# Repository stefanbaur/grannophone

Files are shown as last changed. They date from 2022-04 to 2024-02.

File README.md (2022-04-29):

# Grannophone

This is the repository for Grannophone code snippets and hardware plans.

The main project website can be found at https://www.grannophone.de

Shield: [][cc-by-nc-sa]

This work is licensed under a
[Creative Commons Attribution-NonCommercial-ShareAlike 4.0 International License][cc-by-nc-sa].

[][cc-by-nc-sa]

[cc-by-nc-sa]: http://creativecommons.org/licenses/by-nc-sa/4.0/
[cc-by-nc-sa-image]: https://licensebuttons.net/l/by-nc-sa/4.0/88x31.png
[cc-by-nc-sa-shield]: https://img.shields.io/badge/License-CC%20BY--NC--SA%204.0-lightgrey.svg

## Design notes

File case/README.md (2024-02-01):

# Grannophone plywood case

This directory contains the plans for a plywood case.

Note that this is a work in progress. Most sheets should be usable already, but may lack information about where to drill holes when using a fretsaw/scrollsaw, and where to place screws.
The sheets *should* work with a lasercutter, too (if you use the SVG versions instead of the PDF ones) - feedback welcome!
Note that for lasercutting, you should use the individual SVG files and arrange them to match the size of the plywood sheets you have available. We tried auto-generating merged SVGs for the more common sizes, but the merge tool never really worked.

At present, the base model consists of the following sheets:

- scale check - print/lasercut this first, to check that your printer is printing/your lasercutter ist cutting everything to scale (for lasercutting: if you don't want to waste a sheet of plywood, check if your lasercutter's beam intensity can be set low enough to cut/engrave paper without setting it on fire)
	- sheet_0.pdf

- telephone hook for the Digitus USB telephone receiver/headset
	- sheet_1_digitus.pdf
	- sheet_2_digitus.pdf
	- sheet_3_digitus.pdf - this sheet is needed twice! As with sheets 5 and 6 from the siedle_noamp series, you can simply attach two sheets (good sides facing each other) with masking tape and cut two sheets at the same time.
        - sheet_3_digitus_gespiegelt.pdf - this is a mirrored and partially stripped version of sheet 3 for easier lasercutting.

- telephone hook for the OpisTech telephone receiver/handset (with t-coil hearing aid support)
	- sheet_1_opistech.pdf
	- sheet_2_opistech.pdf
	- sheet_3_opistech.pdf - this sheet is needed twice! As with sheets 5 and 6 from the siedle_noamp series, you can simply attach two sheets (good sides facing each other) with masking tape and cut two sheets at the same time.
        - sheet_3_opistech_gespiegelt.pdf - this is a mirrored and partially stripped version of sheet 3 for easier lasercutting.

- base plates to accommodate two Siedle speakers, connected directly to the SBC, no amplifier
	- sheet_4_siedle_noamp.pdf
	- sheet_5_siedle_noamp.pdf
	- sheet_6_siedle_noamp.pdf - place this sheet on top of sheet 5, firmly secure them by wrapping them with masking tape, and start drilling/sawing/filing - this will help reduce splintering, and the affected areas on sheet 5 will be cut out later on anyway.

- base plates to accommodate two Visaton K50 WP speakers, connected directly to the SBC (or via amplifier, if you find one that works with them)
	- sheet_4_visaton_waveshare.pdf
	- sheet_5_visaton.pdf - place this sheet on top of sheet 4, it is exactly the same, except for missing the cutout for the audio plug that's on sheet_4_visaton.pdf (and you could actually cut that out of sheet_5_visaton.pdf as well, it wouldn't matter)
	- sheet_6_visaton_waveshare.pdf - place this sheet on top of sheets 4 and 5, firmly secure all of them by wrapping them with masking tape, and start drilling/sawing/filing - this will help reduce splintering, and the affected areas on sheets 4 and 5 will be cut out later on anyway.

- base plates to accommodate two VECO 40KS04PN-1 speakers, connected to a DAC/amplifier hat (e.g. HiFiBerry MiniAmp, or WaveShare WM8960) 
	- sheet_4_veco.pdf - place this sheet on top of sheet 5, as sheets 4 and 6 need the same octagonal cutouts (sheet 4 has some connections between them, though, so you will need to work on that separately)
	- sheet_5_veco.pdf - this sheet has rectangular cutouts and is thus the least critical of them all
	- sheet_6_veco.pdf - place this sheet on top of sheets 4 and 5, firmly secure all of them by wrapping them with masking tape, and start drilling/sawing/filing - this will help reduce splintering, and the affected areas on sheets 4 and 5 will be cut out later on anyway.

- base plates to accommodate two WaveShare WM8960 speakers, connected to the WaveShare amplifier hat
	- sheet_4_visaton_waveshare.pdf
	- sheet_5_waveshare.pdf - place this sheet on top of sheet 4, it is exactly the same, except for missing the cutout for the audio plug that's on sheet_4_visaton.pdf (and you could actually cut that out of sheet_5_visaton.pdf as well, it wouldn't matter)
	- sheet_6_visaton_waveshare.pdf - place this sheet on top of sheets 4 and 5, firmly secure all of them by wrapping them with masking tape, and start drilling/sawing/filing - this will help reduce splintering, and the affected areas on sheets 4 and 5 will be cut out later on anyway.

- currently generic parts
	- sheet_7.pdf
	- sheet_8.pdf
	- sheet_8_buttons.pdf - has an asymmetric display position with room for optional cutouts for 2-3 buttons (up/select/down)

- backplates for Digitus and OpisTech handset variants
	- sheet_9_digitus.pdf
	- sheet_9_digitus_visaton.pdf - same as above, but with cutouts for Visaton SC 5.9 ND speakers (these require a DAC/amplifier hat/amplifier)
	- sheet_9_digitus_waveshare.pdf - same as above, but with cutouts for WaveShare WM8960 speakers, connected to the WaveShare amplifier hat
	- sheet_9_opistech.pdf
	- sheet_9_opistech_visaton.pdf - same as above, but with cutouts for Visaton SC 5.9 ND speakers (these require a DAC/amplifier hat/amplifier)
	- sheet_9_opistech_waveshare.pdf - same as above, but with cutouts for WaveShare WM8960 speakers, connected to the WaveShare amplifier hat

- optional templates
	- a3_a5_position_marker.pdf - this draws little boxes in each corner of four DIN A5 sheets arranged in DIN A3 landscape mode - useful if you want to use masking tape on the bottom of your lasercutter to position your plywood sheets (use minimum power/engraving rather than cutting mode so you don't damage your device)
	- cut_a3_into_4_times_a5.pdf - a template to cut a DIN A3 sheet into four DIN A5 sheets - useful if you're using a lasercutter, as the larger sheets of plywood tend to warp easily
	- cut_a3_into_4_times_a5_with_corner_markers.pdf - a combination of the two templates listed above

Shield: [][cc-by-nc-sa]

This work is licensed under a
[Creative Commons Attribution-NonCommercial-ShareAlike 4.0 International License][cc-by-nc-sa].

[][cc-by-nc-sa]

[cc-by-nc-sa]: http://creativecommons.org/licenses/by-nc-sa/4.0/
[cc-by-nc-sa-image]: https://licensebuttons.net/l/by-nc-sa/4.0/88x31.png
[cc-by-nc-sa-shield]: https://img.shields.io/badge/License-CC%20BY--NC--SA%204.0-lightgrey.svg

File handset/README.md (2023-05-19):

# Grannophone plywood case

This directory contains the plans for a plywood handset.

Note that this is a work in progress. Most sheets should be usable already, but may lack information about where to drill holes when using a fretsaw/scrollsaw, and where to place screws. Screw positions may also be entirely wrong.
The sheets *should* work with a lasercutter, too (if you use the SVG versions instead of the PDF ones) - feedback welcome!
Note that for lasercutting, you should use the individual SVG files and arrange them to match the size of the plywood sheets you have available. We tried auto-generating merged SVGs for the more common sizes, but the merge tool never really worked.

At present, the base model consists of the following sheets:

- scale check - print this first, to check that your printer is printing everything to scale
	- ../case/sheet_0.pdf

- handset based on the EKULIT 210030 (ETR-35/21A) dynamic receiver (alternatively a VISATON K16 50 Ohm speaker) and a Siedle STS/CTB 711-... (200019224-00) electret microphone. The handset should work as a drop-in replacement for the Digitus one, but will require a USB soundcard and a shielded audio cable with a TRRS plug (plus a TRRS - 2 x TRS splitter cable if your USB soundcard has separate ports for Audio in and Audio out). Note that there are two gaps in the two middle layers that SHOULD be large enough to fit two pairs of WAGO 221-2411 cage clamps, but they MUST be inserted *horizontally* (i.e. with their orange "wings" folded flat in and pointing *to the left and right*, NOT upwards).
        - sheet_a_ekulit_visaton_siedle_wago_trrs.pdf
        - sheet_b_ekulit_visaton_siedle_wago_trrs.pdf

- handset based on all the above, but integrating a DELOCK 65453 TRRS-to-terminalblock adapter and a USB-TRRS soundcard directly into the receiver, using a USB extension cord to further mimic the Digitus receiver.
LOGILINK UA0299
        - sheet_a_ekulit_visaton_siedle_delock_logilink_usb.pdf
        - sheet_b_ekulit_visaton_siedle.delock_logilink_usb.pdf

- optional templates
	- ../case/a3_a5_position_marker.pdf - this draws little boxes in each corner of four DIN A5 sheets arranged in DIN A3 landscape mode - useful if you want to use masking tape on the bottom of your lasercutter to position your plywood sheets (use minimum power/engraving rather than cutting mode so you don't damage your device)
	- ../case/cut_a3_into_4_times_a5.pdf - a template to cut a DIN A3 sheet into four DIN A5 sheets - useful if you're using a lasercutter, as the larger sheets of plywood tend to warp easily
	- ../case/cut_a3_into_4_times_a5_with_corner_markers.pdf - a combination of the two templates listed above

Shield: [][cc-by-nc-sa]

This work is licensed under a
[Creative Commons Attribution-NonCommercial-ShareAlike 4.0 International License][cc-by-nc-sa].

[][cc-by-nc-sa]

[cc-by-nc-sa]: http://creativecommons.org/licenses/by-nc-sa/4.0/
[cc-by-nc-sa-image]: https://licensebuttons.net/l/by-nc-sa/4.0/88x31.png
[cc-by-nc-sa-shield]: https://img.shields.io/badge/License-CC%20BY--NC--SA%204.0-lightgrey.svg

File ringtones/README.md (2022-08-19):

# Grannophone ringtones

This directory contains some sample soundfiles that can be used as ringtones.

They mechanical ringtones were all recorded by Stefan Baur (https://github.com/stefanbaur), using a mechanical cash register bell as the source of the sound.

The spoken "incoming call" messages in German and English (eingehender_anruf_kris_rothe.wav and incoming_call_kris_rothe.wav) were kindly provided by Kristina Rothe (https://www.kristina-rothe.com/).

Shield: [][cc-by-nc-sa]

This work is licensed under a
[Creative Commons Attribution-NonCommercial-ShareAlike 4.0 International License][cc-by-nc-sa].

[][cc-by-nc-sa]

[cc-by-nc-sa]: http://creativecommons.org/licenses/by-nc-sa/4.0/
[cc-by-nc-sa-image]: https://licensebuttons.net/l/by-nc-sa/4.0/88x31.png
[cc-by-nc-sa-shield]: https://img.shields.io/badge/License-CC%20BY--NC--SA%204.0-lightgrey.svg

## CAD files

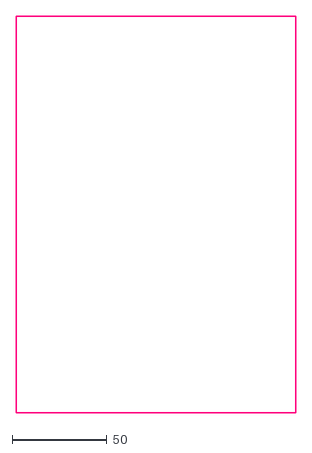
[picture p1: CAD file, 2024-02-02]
2024-02-02_P4V1/sheet_0.dxf
147.6 x 209.6

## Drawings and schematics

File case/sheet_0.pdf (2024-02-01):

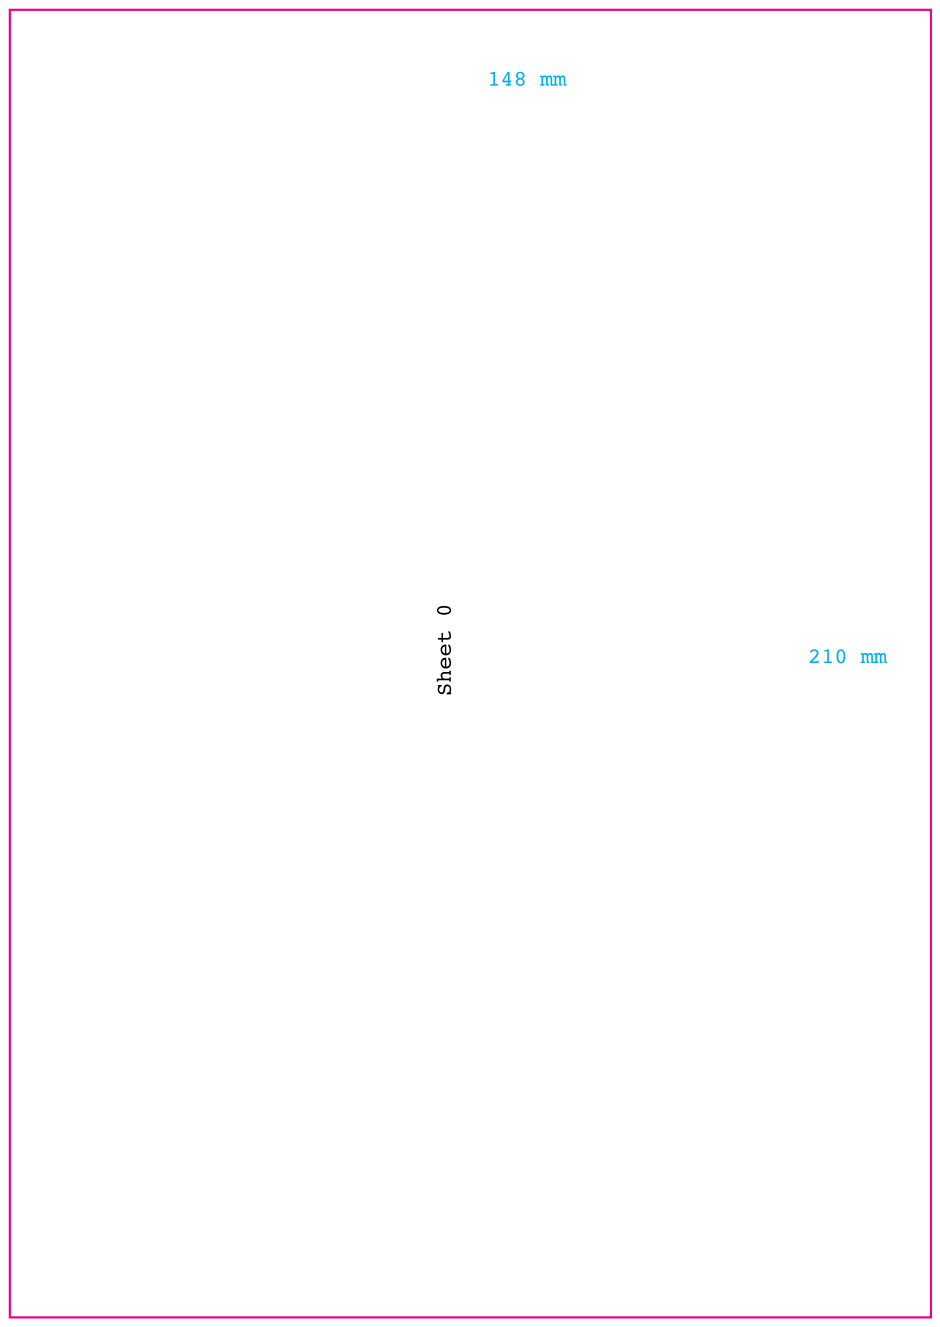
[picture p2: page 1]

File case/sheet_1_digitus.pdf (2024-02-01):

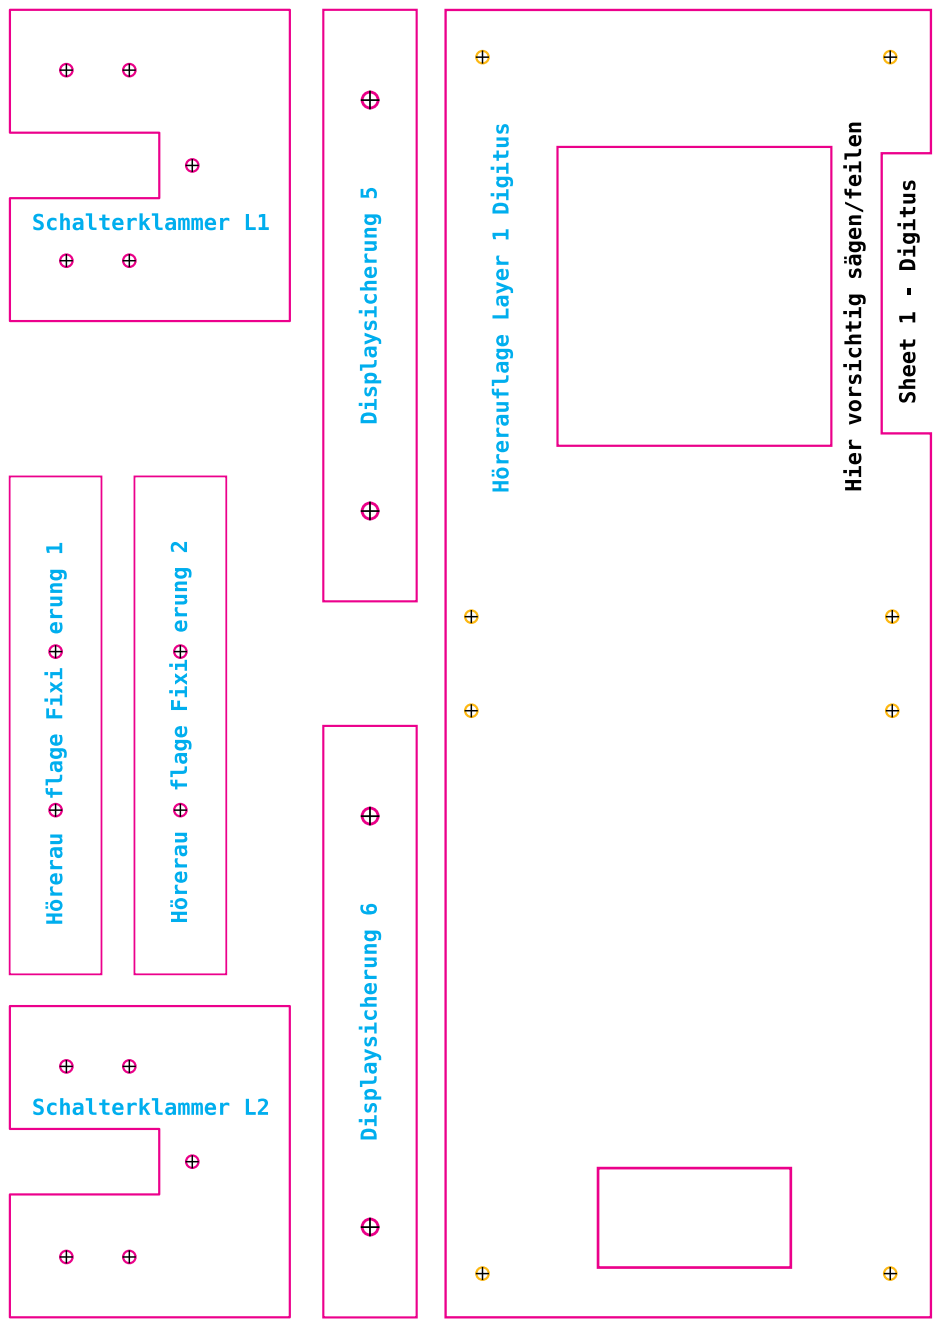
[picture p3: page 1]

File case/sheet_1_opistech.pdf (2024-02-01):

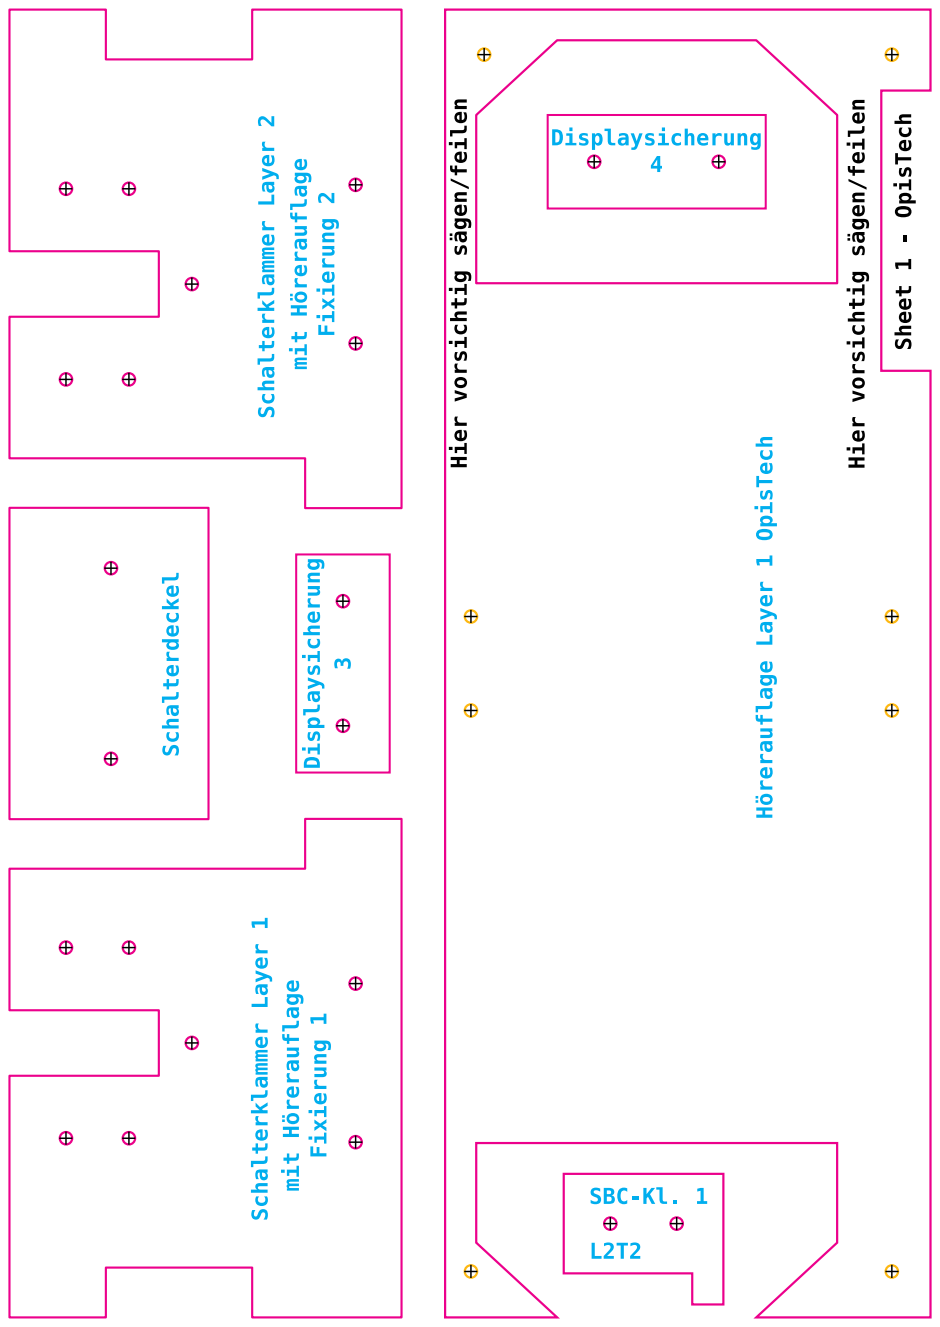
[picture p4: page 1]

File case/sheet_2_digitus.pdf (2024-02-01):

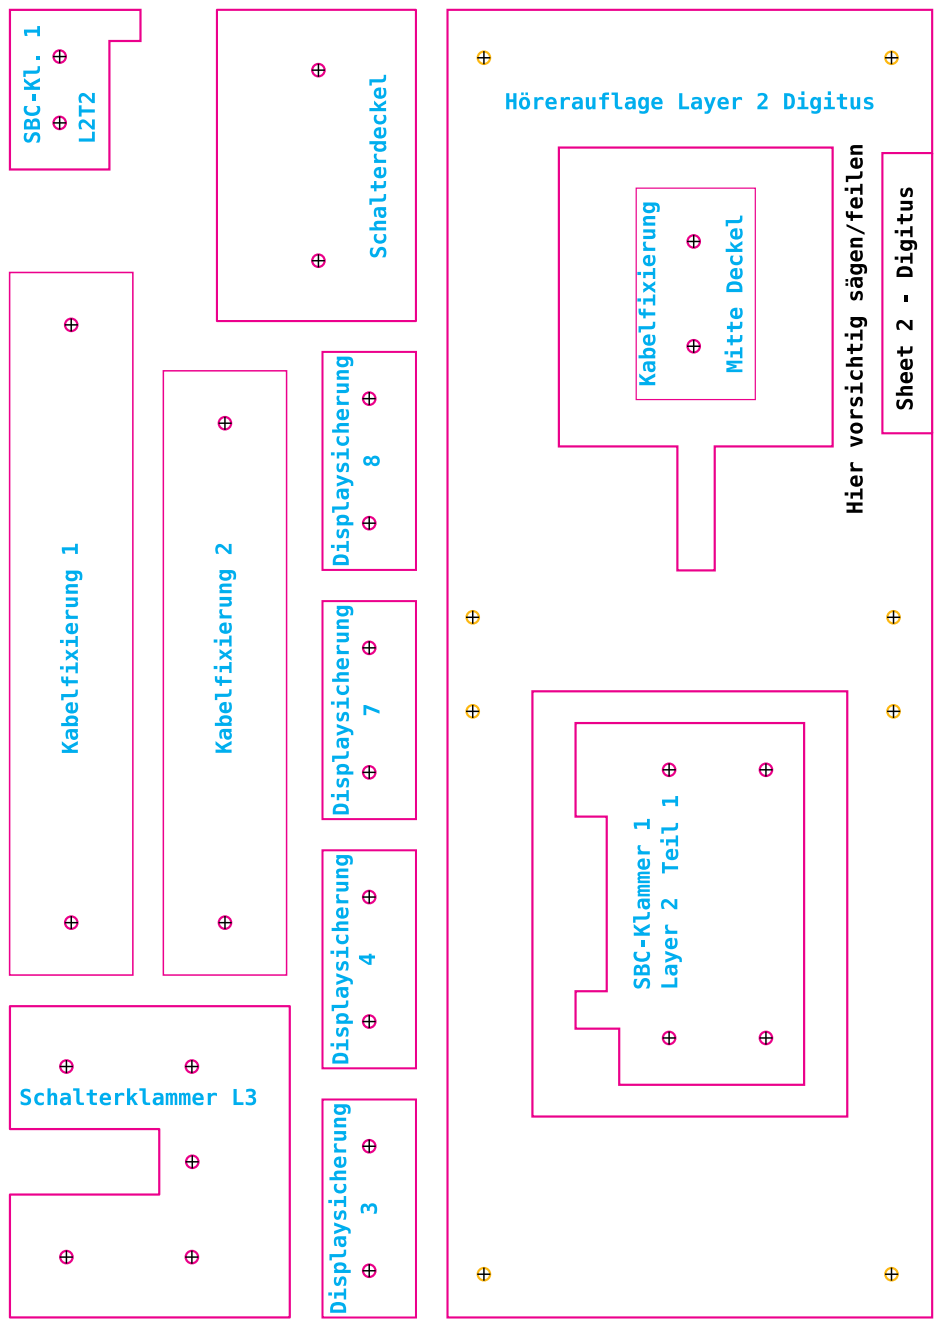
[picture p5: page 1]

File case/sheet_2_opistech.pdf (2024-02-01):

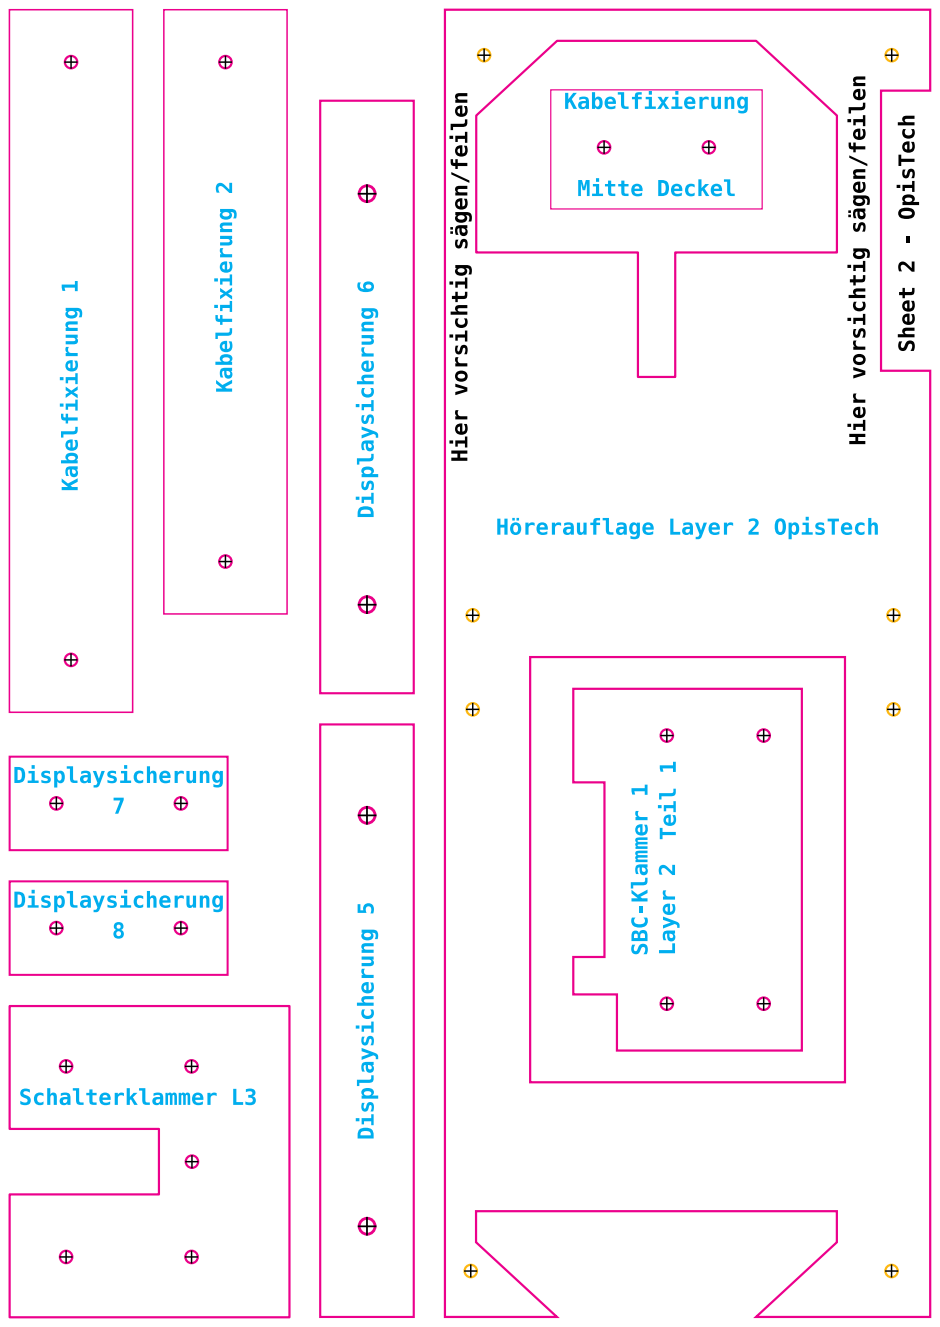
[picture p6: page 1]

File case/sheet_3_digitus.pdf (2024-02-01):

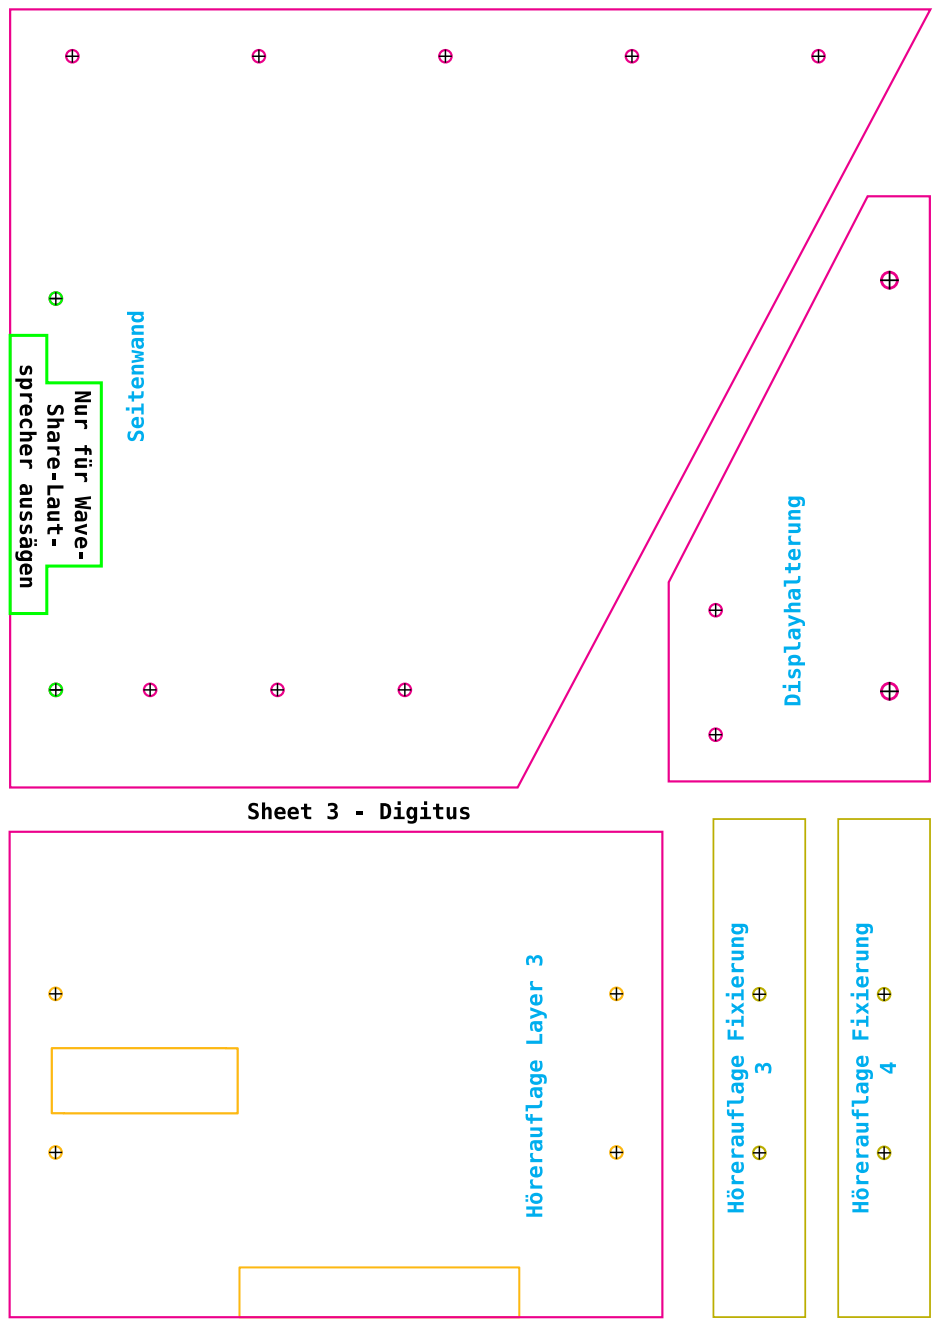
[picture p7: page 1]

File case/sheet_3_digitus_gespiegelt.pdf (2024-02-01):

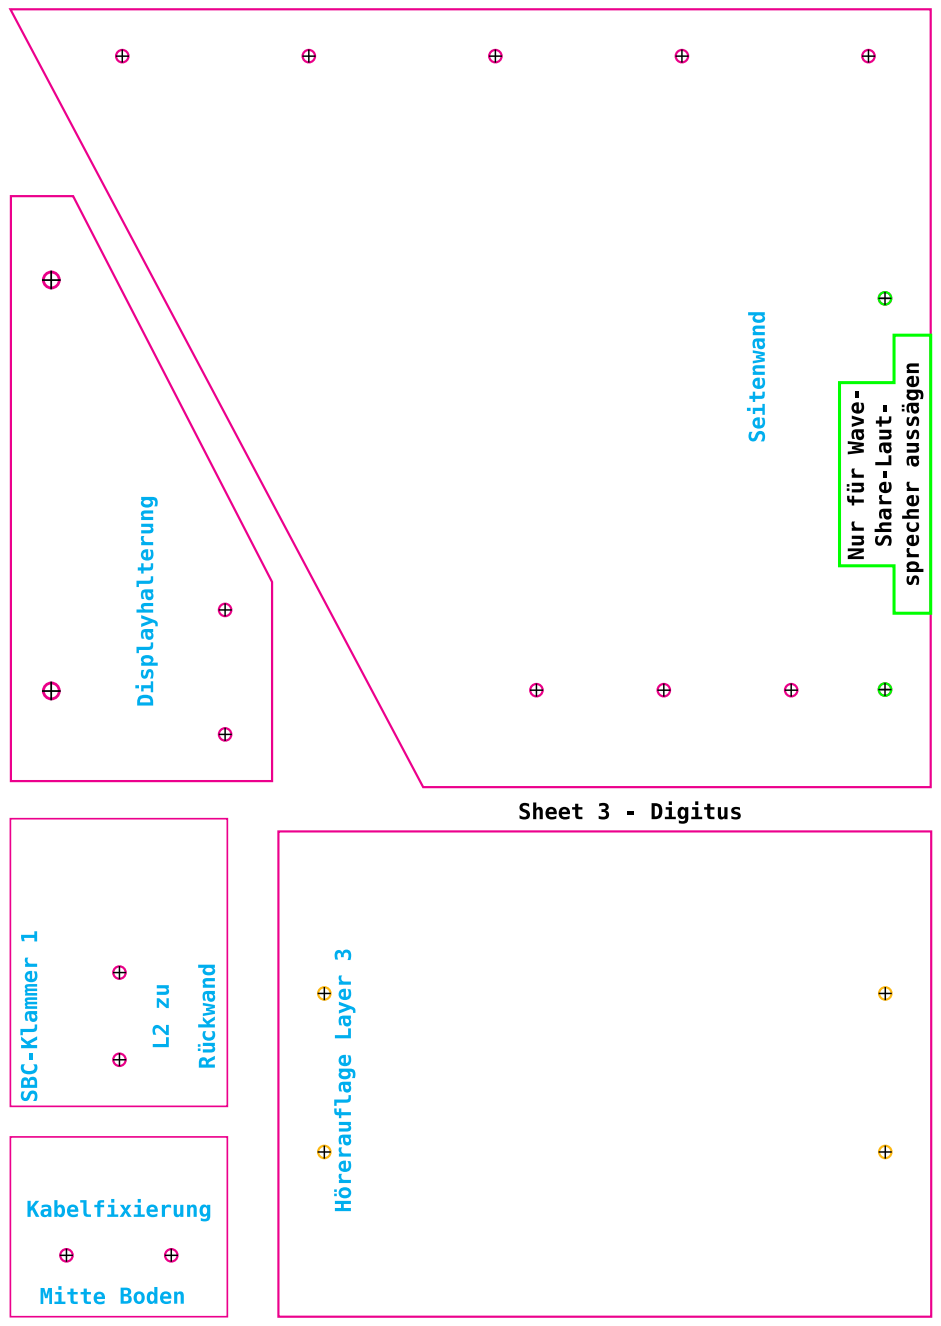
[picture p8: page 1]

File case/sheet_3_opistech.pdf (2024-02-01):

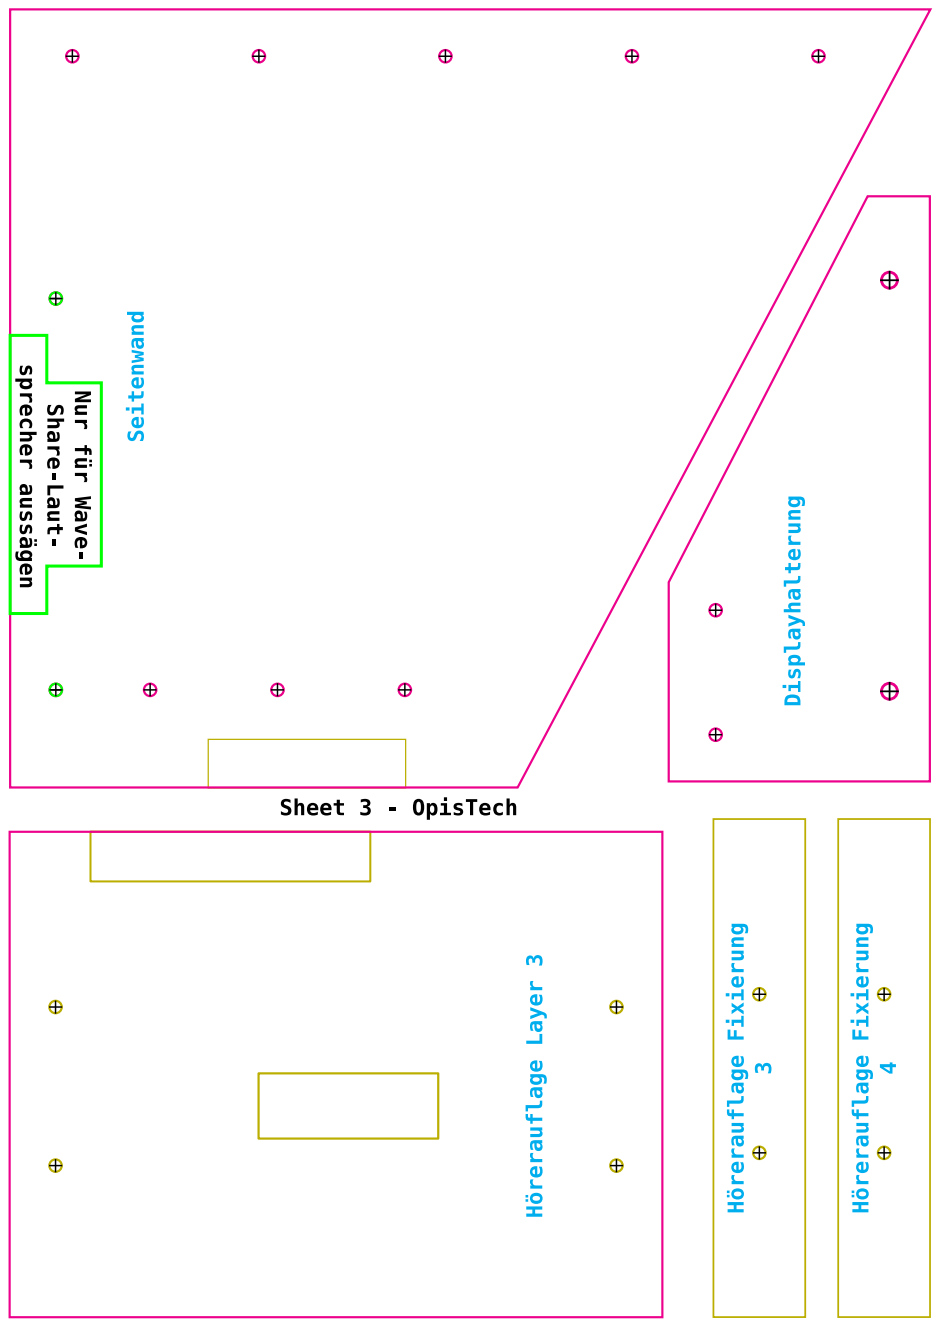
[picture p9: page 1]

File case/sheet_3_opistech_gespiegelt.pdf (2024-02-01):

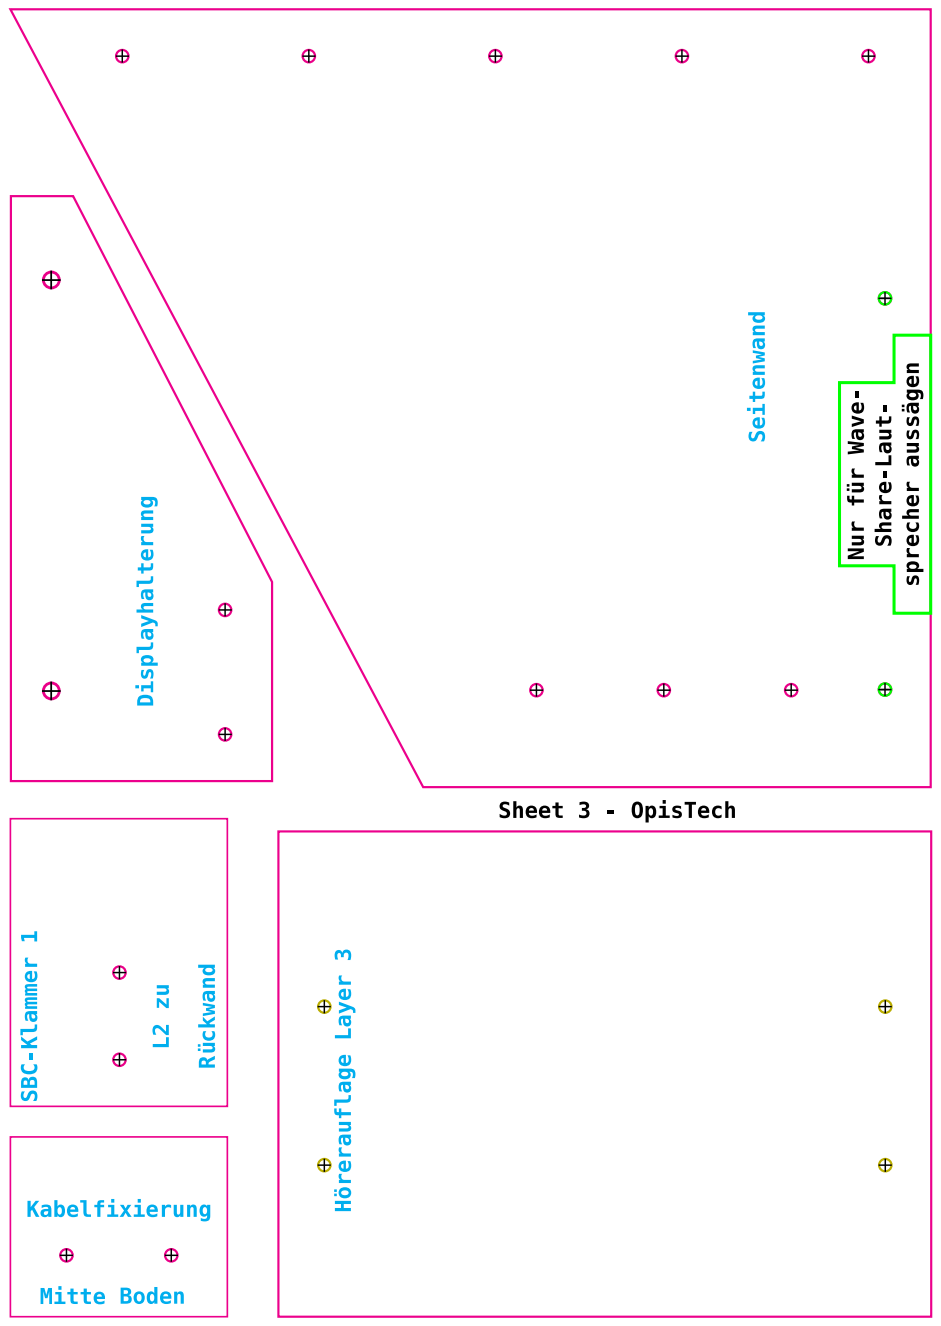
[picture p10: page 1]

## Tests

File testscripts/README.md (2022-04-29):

# Grannophone test and demo scripts

This directory contains some test and demo scripts.

They can be used to test GPIO button functions, controlling LEDs via GPIO, displaying fullscreen messages on the TFT (for demos/mockups), etc.
None of these scripts are needed for regular/production use.

Shield: [][cc-by-nc-sa]

This work is licensed under a
[Creative Commons Attribution-NonCommercial-ShareAlike 4.0 International License][cc-by-nc-sa].

[][cc-by-nc-sa]

[cc-by-nc-sa]: http://creativecommons.org/licenses/by-nc-sa/4.0/
[cc-by-nc-sa-image]: https://licensebuttons.net/l/by-nc-sa/4.0/88x31.png
[cc-by-nc-sa-shield]: https://img.shields.io/badge/License-CC%20BY--NC--SA%204.0-lightgrey.svg

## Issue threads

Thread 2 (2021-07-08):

User Interface ideas

shnydercom, 2021-07-08:
Saw it on heise.de, and saw there are some ideas for physical user interface, collected them and added my software-ideas below
- telephone dial
- size-increaser/magnifying glass

Hardware interfaces
- Bluetooth-connection to hearing aids

Software ideas:
- internal personal telephone book, that contains names, images and **old** telephone numbers of friends and relatives on the device, and connects them with a video-callable account

stefanbaur, 2021-07-13:
Hi, this is just to let you know that your comment has been noticed by me. I am currently a bit overwhelmed by the feedback after the Grannophone was mentioned on heise -- especially as it is only a personal side project, not my day job. It may take a while until I get to come up with a meaningful reply. Sorry.

shnydercom, 2021-07-14:
sure, I just intended this as a place to dump, discuss and structure some ideas - since the heise forum is a bit short-lived. Great work by the way :)

stefanbaur, 2022-04-06:
Hi. Unfortunately, some personal issues on my end delayed work on the Grannophone project. However, I am now trying to pick up where I left. I have finally been able to set up a (German-language) mailing list for it. If you happen to speak/understand German, you might want to subscribe there. It's currently the second link from the bottom on this page: https://www.grannophone.de/

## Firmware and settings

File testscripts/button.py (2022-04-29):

# -*- coding: utf-8 -*-
from RPi import GPIO
from datetime import datetime
import os, time
 
 
GPIOPin = 4
 
def button_callback(gpio_number):
    #print("Button pressed!")
    datetime_string = datetime.now().strftime("%Y-%m-%d %H-%M-%S %s")
    print("Button pressed at %s!" % datetime_string)
    #filename = "/home/pi/button_pushed_at_%s.txt" % datetime_string
    #os.system("touch %s" % filename)
 
GPIO.setmode(GPIO.BCM)
GPIO.setup(GPIOPin, GPIO.IN, pull_up_down = GPIO.PUD_DOWN)
#GPIO.add_event_detect(GPIOPin, GPIO.RISING, callback=button_callback,bouncetime=500)
GPIO.add_event_detect(GPIOPin, GPIO.FALLING, callback=button_callback,bouncetime=500)
 
try:
    while True:
        time.sleep(0.01)
except:
    GPIO.cleanup()

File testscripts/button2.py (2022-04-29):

import RPi.GPIO as GPIO
import threading

class ButtonHandler(threading.Thread):
    def __init__(self, pin, func, edge='both', bouncetime=200):
        super().__init__(daemon=True)

        self.edge = edge
        self.func = func
        self.pin = pin
        self.bouncetime = float(bouncetime)/1000

        self.lastpinval = GPIO.input(self.pin)
        self.lock = threading.Lock()

    def __call__(self, *args):
        if not self.lock.acquire(blocking=False):
            return

        t = threading.Timer(self.bouncetime, self.read, args=args)
        t.start()

    def read(self, *args):
        pinval = GPIO.input(self.pin)

        if (
                ((pinval == 0 and self.lastpinval == 1) and
                 (self.edge in ['falling', 'both'])) or
                ((pinval == 1 and self.lastpinval == 0) and
                 (self.edge in ['rising', 'both']))
        ):
            self.func(*args)

        self.lastpinval = pinval
        self.lock.release()

def real_cb(gpio_number):
    datetime_string = datetime.now().strftime("%Y-%m-%d %H-%M-%S %s")
    print("Button pressed at %s!" % datetime_string)

GPIO.setmode(GPIO.BCM)
GPIO.setup(4, GPIO.IN, pull_up_down=GPIO.PUD_DOWN)
cb = ButtonHandler(4, real_cb, edge='rising', bouncetime=100)
cb.start()
GPIO.add_event_detect(4, GPIO.RISING, callback=cb)

try:
    while True:
        time.sleep(0.01)
except:
    GPIO.cleanup()

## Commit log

2022-04-29 renamed sheets 1-3 and sheets 4-6 to indicate the case variant they are designed for
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2022-05-03 completely re-did SBC cutout, changed size of SBC clamp, changed dashed line to hairline
2022-05-05 typofix, changed notice from cyan to black, reduced height (actually, width, once mounted) of "nose" on lower left part, changed cyan texts to "bold"
2022-05-05 increased size by 5mm, changed cyan texts to "bold"
2022-05-08 shortened display clamps, added drill hole markers
2022-05-08 reduced width of topmost receiver rest layer to better accommodate display frame, increased size of microphone "dimple"
2022-05-08 added drill hole markers, completely redesigned SBC clamp on lower right
2022-05-08 undid previous change - back to 10mm on the left
2022-05-08 increased size to 11mm on the left
2022-05-08 redesigned SBC Clamp 1 Layer 1, added new part for SBC Clamp 1 Layer 2
2022-05-08 added drill hole markers
2022-05-08 added more drill hole markers, switched parts that need to be cut only once to yellow (sheet 3 needs to be cut twice)
2022-05-08 fixed drill hole markers where cross was behind magenta-colored dot
2022-05-17 darkened yellow for better visibility in black and white prints
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2022-05-27 fixed drillhole positions
2022-05-27 completely redesigned display arresting clamps, fixed camera holder notch
2022-05-27 shortened display arresting clamp, reduced size of receiver rest layer to better accommodate display frame, added/repositioned various drillhole markers
2022-05-27 increased size of "elephant ears" to better accommodate loudspeaker coils/magnets
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2022-05-27 some slight adjustments to SBC cutout, and removed 1mm from the front side to better accommodate display frame
2022-05-27 flipped SBC clamp 1 parts and rearranged camera case parts accordingly (so all labels are visible during assembly), added various drillholes, increased frame cutout for display by 2mm, moved entire c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
2022-05-27 updated lasercut templates (created from individual SVGs/PDFs)
2023-02-18 New versions of sheet 0 to fix issues with some lasercutters
2023-03-25 this file can be used to cut a DIN A3 sized sheet of plywood into four DIN A5 sized ones.
2023-03-25 updated all sheets, new crosshairs for drill holes (should work for lasercutting as well as manual drilling), new texts (as paths - for easier lasercutting)
2023-03-25 added mirrored (and partially stripped) versions of the two sheet_3 variants for easier lasercutting
2023-03-25 updated info to match currently available files
2023-03-25 lasercut svg and pdf files have been removed, as the merging tool that created them from the individual files caused some trouble. For lasercutting, please grab the individual SVGs and arrange them t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
2023-03-25 added more info re:lasercutting and mirrored sheets
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2023-04-08 moved cutout for hook switch by 2mm
2023-04-08 moved cutout for hook switch by 4mm and for camera mount by 7mm
2023-04-08 forced DIN A5 size, fixed positions of hook switch on sheet 3 and opistech sheets
2023-04-16 reworked sheet 8 - rearranged parts, camera frame got longer legs and drill holes
2023-04-16 moved/fixed receiver position for opistech, enlarged camera cable passthrough
2023-04-16 added some more files that are helpful when using a lasercutter
2023-04-16 changed display mount drillholes to 3mm
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2023-04-16 updated/changed display clamp labels
2023-04-17 added/relocated several drill holes, added gap for audio plug on visaton sheet
2023-04-17 moved description so it does not collide with drill hole
2023-04-17 added several drill holes
2023-04-17 added Visaton-specific cuts and drill holes
2023-04-23 updated backplanes for digitus and opistech variants - speaker cutouts/clamps were wrong
2023-04-25 added front panel drillholes
2023-04-25 added spacers for speaker mounts
2023-04-28 removed 2mm from the front for better fit
2023-04-28 massive rework, repositioned drillholes, resized some parts
2023-04-28 repositioned drillholes to avoid collisions while maintaining an even/symmetric distribution
2023-05-05 resized and rearranged display guards, added cutout to hook switch clamps
2023-05-05 resized hook rest layer 3 and added drillholes
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2023-05-05 slightly resized display frame
2023-05-05 repositioned display frame cutout/drillholes
2023-05-05 added cutout for SBC clamp 1 layer 2 part 1
2023-05-05 drillholes were 3mm instead of 2.5mm, fixed now. also added new drillholes for camera mount.
2023-05-05 repositioned SBC clamp and its cutout position
2023-05-13 massive rework after last lasercut run, should fix most of the open issues
2023-05-13 more speaker clamps, more labels, more drillholes ...
2023-05-14 various updates - drillhole positions, part shapes, etc. - most of it should fit now, but I have a gut feeling that some drillhole positons are still wrong.
2023-05-15 removed "text" and "flowroot" remains from SVG
2023-05-15 Completely reworked VISATON SC 5.9 ND speaker mounts ... again.
2023-05-17 resized/repositioned opistech switch cutout
2023-05-17 shortened SBC clamp
2023-05-17 rotated and repositioned SBC clamp 2 layers 1 and 2
2023-05-17 slightly enlarged speaker frames
2023-05-17 removed speaker bars/clamps, no longer needed
2023-05-18 SBC clamp 1 L1 rear part now on sheet 7, rearranged parts
2023-05-18 rearranged parts to make space for longer cable clamps
2023-05-18 cable clamps are now exactly 105mm
2023-05-18 repositioned drillholes on SBC clamps
2023-05-18 updated clamp sizes/shapes, drillhole positions,text positions
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2023-05-19 increased cutout size by .5 mm, was too tight
2023-05-19 increased cutout size by 1 mm, was too tight
2023-05-19 various fixes after first lasercut, mostly drillhole positions and larger "chambers" for WAGO connectors
2023-05-19 larger "chambers" fix for WAGO connectors was incomplete
2023-05-20 resized SBC clamp 2
2023-05-20 added drillholes on layer 3
2023-05-20 added cutout for 40-pin plug (old IDE standard that fits GPIO connector)
2023-05-24 added new cable clamp layer
2023-05-24 resized SBC clamp 1 layer 2 part 1 for easier fitting, altered cable fix size (now asymmetrical, but fitting on top of the SBC clamp
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2023-05-24 repositioned drillholes to avoid drillhole/screw collision across multiple planes
2023-05-24 redesigned cutout shapes and repositioned all cutouts for VECO speakers due to insufficient cable length
2023-05-24 refined display mount, added new parts, required some shuffling and rearranging of existing parts
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2023-05-24 shrunk receiver part by 1 mm for easier fit
2023-05-24 slightly increased switch clamp width for easier fit
2023-06-01 initial commit for copper heatsink
2023-06-08 increased spacer size by 1mm each
2023-06-08 added new parts for cable clamps/rear mount
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2023-06-16 made space for M2.5 nuts in case a GPIO sound card is used and needs to be screwed into the main SBC
2023-06-16 space for M2.5 nut was still wrong
2023-06-17 resized and moved speaker cutouts/clamps for WaveShare speakers
2023-06-17 resized and moved speaker cutouts/clamps for WaveShare speakers, degroup, cleanup
2023-06-17 added cutout in SBC clamp to accomodate audio HAT screw
2023-06-17 added drillholes for increased stability
2023-08-12 increased and fused speaker cutouts
2023-08-12 still work in progress, but has all currently required waveshare speaker mounts in the cutout area
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2024-02-01 moved speakers more towards side wall, to make more space for USB devices
2024-02-01 moved speakers more towards side wall, to make more space for USB devices (part 2)
2024-02-01 added sheet 8 version with asymmetric display position to make room for 2-3 buttons
2024-02-01 reverted cutout position change as the version suitable for adding buttons is now a separate file
2024-02-02 testing dxf export with inkscape 0.92
    [sheet_0.dxf]
2024-02-02 testing dxf export with pstoedit
    [sheet_0.dxf]
2024-02-02 testing dxf export with freecad
    [sheet_0.dxf]

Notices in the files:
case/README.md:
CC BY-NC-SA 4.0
